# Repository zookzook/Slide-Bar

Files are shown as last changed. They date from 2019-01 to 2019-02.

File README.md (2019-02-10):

# Slide-Bar

Simple board for a slide potentiometer and visible feedback.

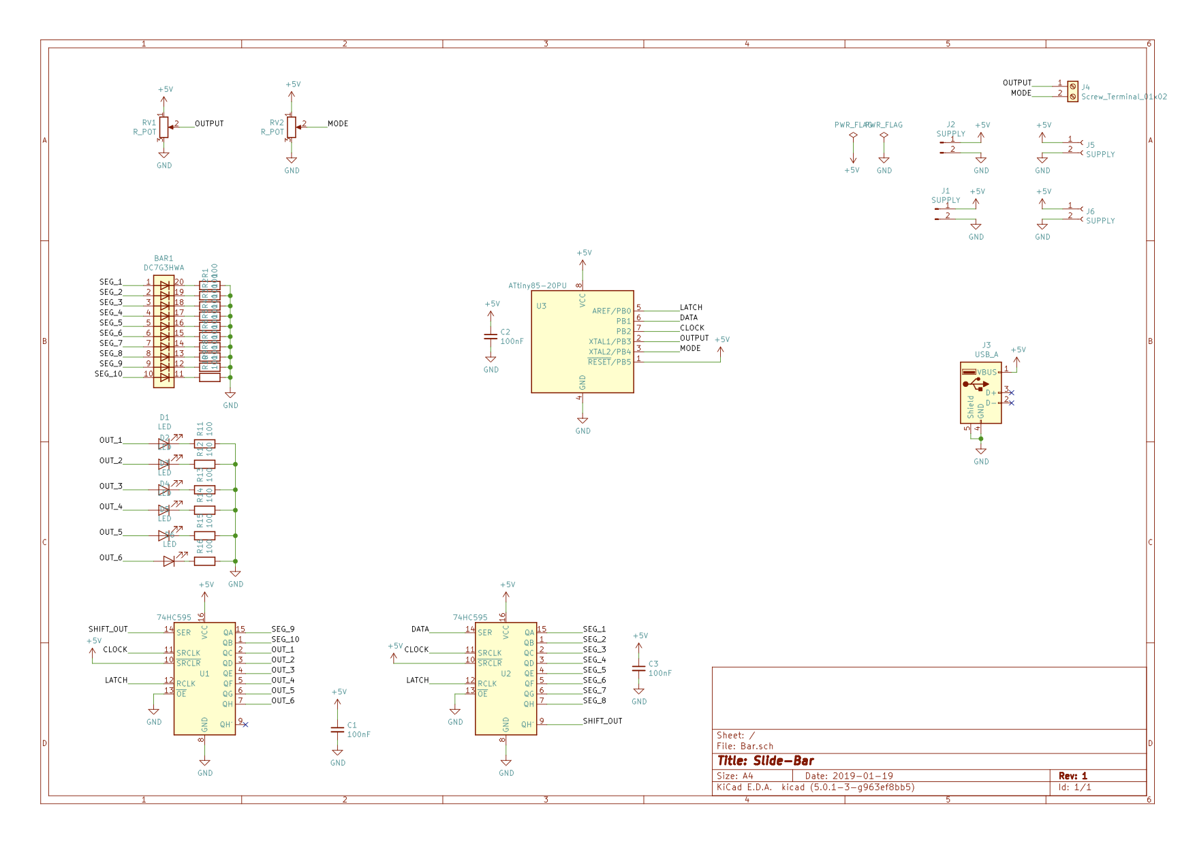
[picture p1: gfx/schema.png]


The idea behind it: With a slide potentionmeter an analog value can be changed. The change or the value is displayed with a bar display (10 LEDs). The board is designed so that you can connect several to each other. The power supply is thus forwarded from board to board.

You can thus combine the components. If you have three of the sliders, you can use the three analog values for one RGB LED. With the three slide potentionmeter thus a certain color can be adjusted.

Okay, that's a bit boring, but great fun for kids. If you add a chic frame and a nice instrument plate to the whole thing, you get a super game for children who like to fiddle around everywhere. Ultimately, that's the idea: a simple game machine and different input components (sliding and turning meters, switches) and output components (RGB LEDs, bar LEDs) with different effects (animated, cursor, Zini mode).

# How does it work?

The whole thing is controlled by an Attiny85 chip. With the help of two shift registers the LEDs are controlled. A rotary potentiometer controls the mode. There are six modes:

1) Standard slider mode: The value is displayed from bottom to top with the LEDs switched on.
2) Analogous to mode 1. The active LEDs are animated pulsatingly. In the red area, the pulse rate is higher.
3) Cursor mode. The value is displayed as a blinking cursor. If the potentiometer is changed, the flashing will be deactivated during the modification time.
4) Zini mode. When the value changes, the cursor moves, pulling a tail behind it. The previously visited LEDs are slowly faded out.
5) still in the planning stage
6) Dropping mode. A cursor is moving from the current position to the first position of the slider.

The power comes from a USB-A cable. Each two pin headers for 5V + and GND are located on the sides, so that the boards can be placed side by side or one below the other.

# Board preview
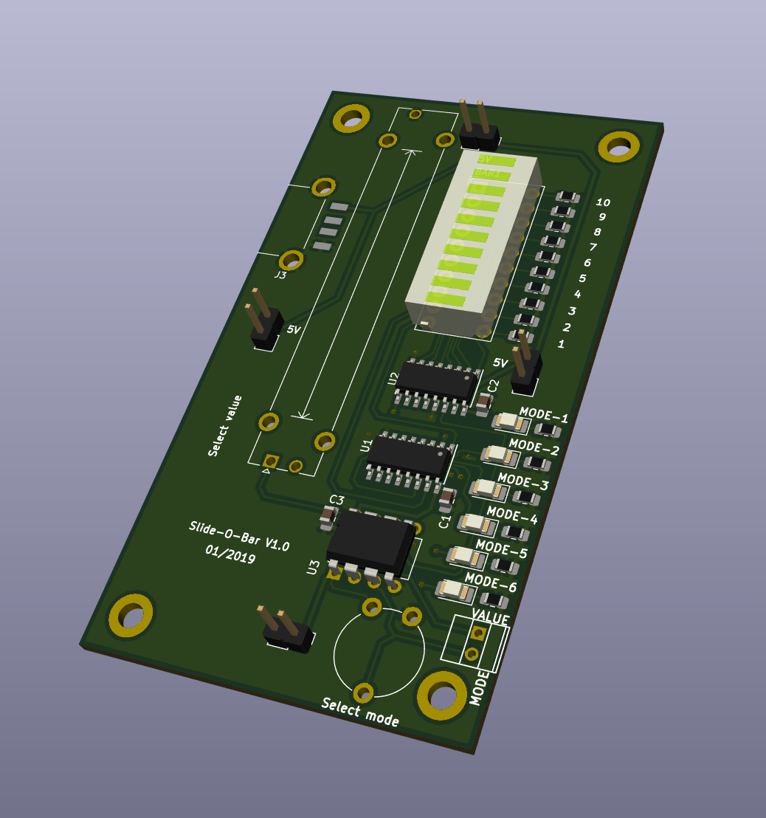
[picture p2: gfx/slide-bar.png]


You can order pretty boards from here: https://aisler.net/p/UGINGUNY

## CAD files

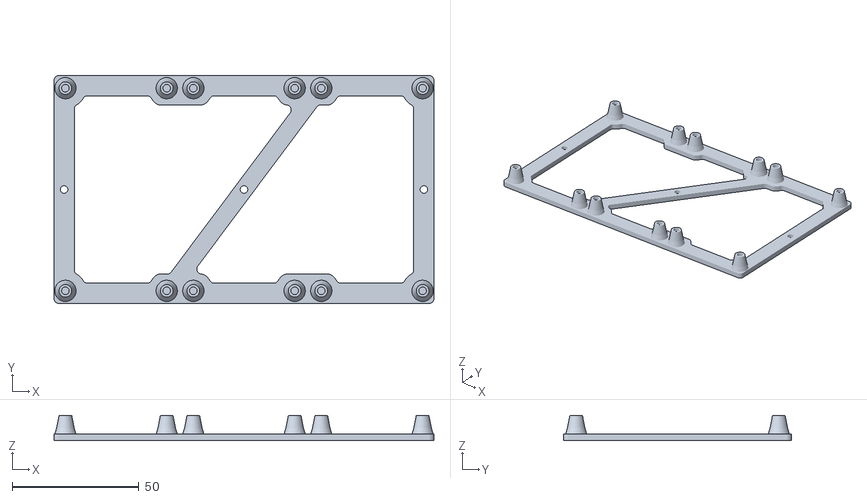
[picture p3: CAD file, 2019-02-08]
stl/mounting-3x.stl
150.0 x 90.0 x 10.0

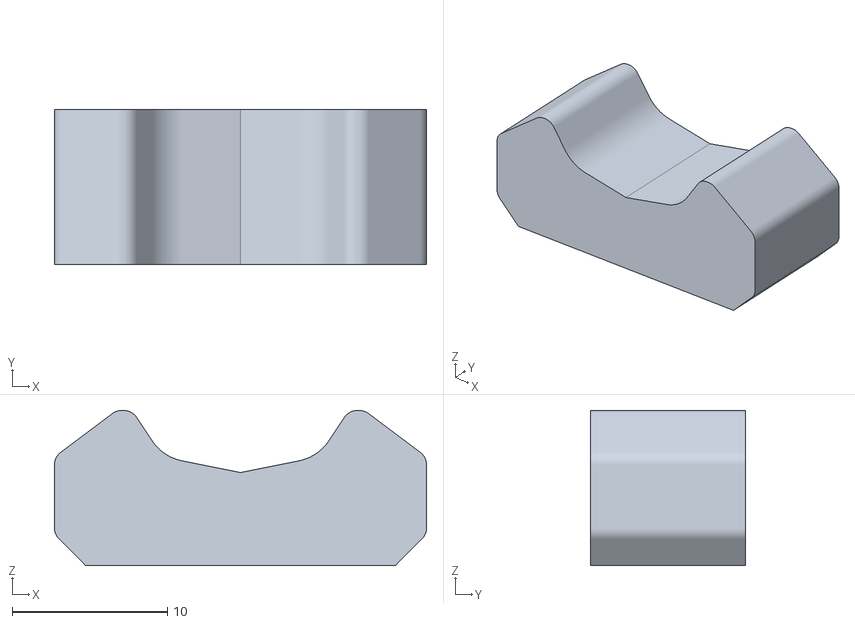
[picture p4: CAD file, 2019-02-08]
stl/slider.stl
24.0 x 10.0 x 10.0

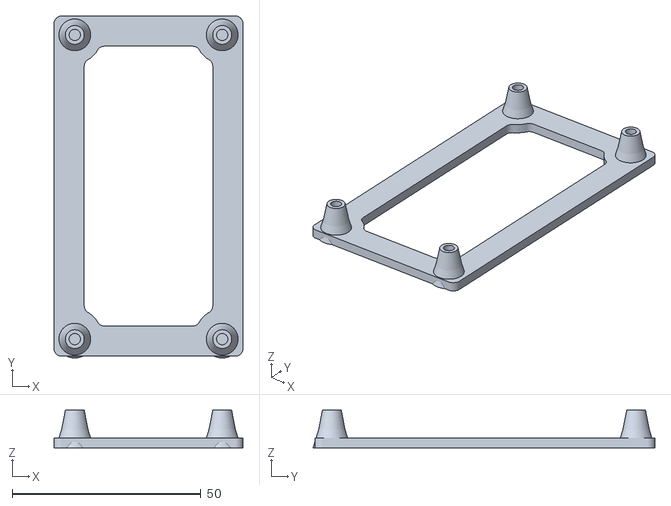
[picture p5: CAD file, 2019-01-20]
stl/mounting-1x.stl
50.0 x 90.5 x 10.0

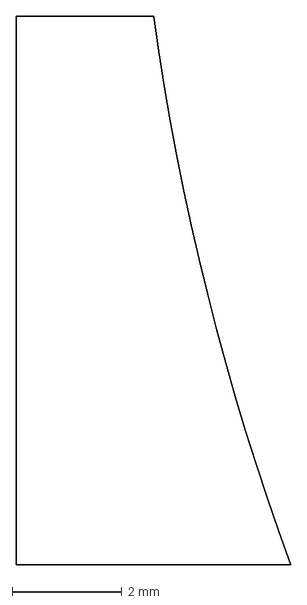
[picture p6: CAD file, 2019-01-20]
dxf/screw-holder.dxf
5.00 x 10.0 mm

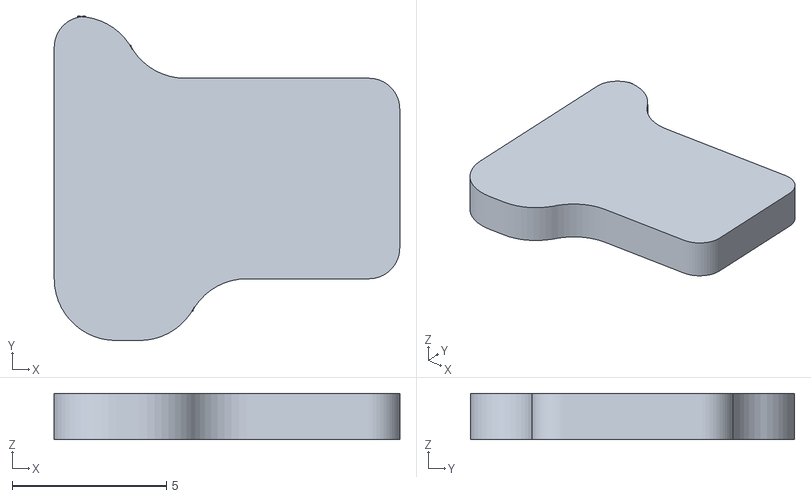
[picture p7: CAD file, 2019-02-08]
stl/washer.stl
11.2 x 10.5 x 1.50

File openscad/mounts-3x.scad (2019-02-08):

width = 50;
height = 90;
dx_1 = 5.5;
dy_1 = 5.5;
st_1 = 2.6;
h = 2.6;

module screw_holder(pos = [0,0,2] ) {
    
    translate(pos)    
    difference() {
        rotate_extrude($fn=50)
            import (file = "../dxf/screw-holder.dxf", layer = "0");
        cylinder(h = 30, r1 = 1.5, r2 = 1.5, $fn = 30, center = true);
    }
}

module mounting() {
    
    difference() {
        union() {
            linear_extrude(height = h, center = false, convexity = 1, twist = 0, slices = 20, scale = 1.0, $fn = 50)
                import (file = "../dxf/mounting-3x.dxf", layer = "0");
            
            for(i = [0 : 1 : 2]) {
                xoffset = i * 50.5;
                xpos = xoffset + 4.5;
                ypos = 5.0;                
                screw_holder([xpos, ypos, 0]);
                screw_holder([xpos + 40, ypos, 0]);
                screw_holder([xpos + 40, ypos + 80, 0]);
                screw_holder([xpos, ypos + 80, 0]);                
            }
        }
        linear_extrude(height = 10, center = true, convexity = 0, twist = 0, slices = 20, scale = 1.0, $fn = 50)
            import (file = "../dxf/mounting-3x.dxf", layer = "out");
        linear_extrude(height = 10, center = true, convexity = 0, twist = 0, slices = 20, scale = 1.0, $fn = 50)
            import (file = "../dxf/mounting-3x.dxf", layer = "out-2");

        rotate([0,0,90])
        translate([0,0,-1])
                cube([90,10,3]);

        rotate([0,0,90])
        translate([0,-(3*50+10),-1])
                cube([90,10,3]);

    }

}


mounting();

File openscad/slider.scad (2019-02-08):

module schieber() {
translate([-10,0,0])
rotate([90,0,0])
        linear_extrude(height = 12, center = true, convexity = 1, twist = 0, slices = 20, scale = 1.0, $fn = 80)
            import (file = "../dxf/slider.dxf", layer = "0");
            
}

module mounting() {
    translate([-2,-1,-0.5])
    cube([4,2,5]);
}

difference() {
    schieber();
    mounting();
}

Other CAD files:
openscad/mounts.scad
openscad/washer.scad
dxf/mounting-1x.dxf
dxf/mounting-3x.dxf
dxf/slider.dxf
dxf/washer.dxf

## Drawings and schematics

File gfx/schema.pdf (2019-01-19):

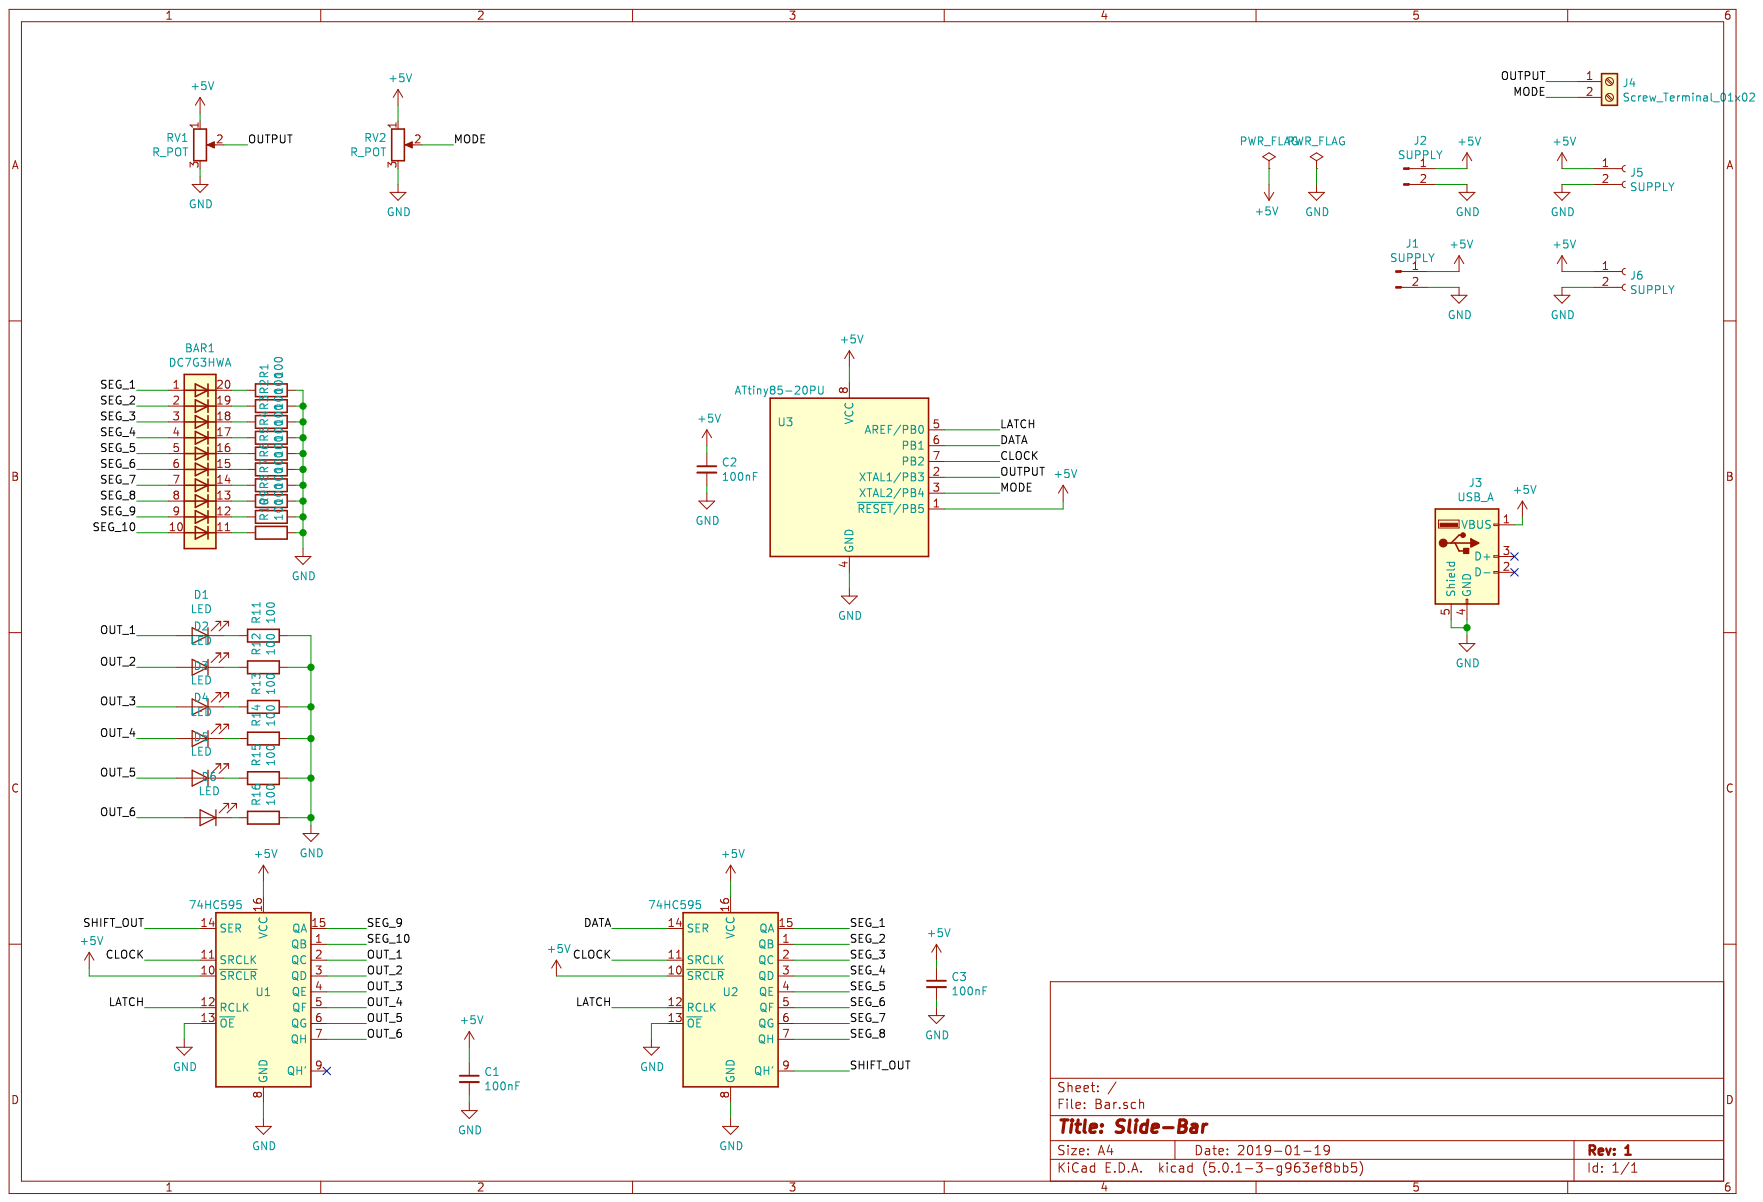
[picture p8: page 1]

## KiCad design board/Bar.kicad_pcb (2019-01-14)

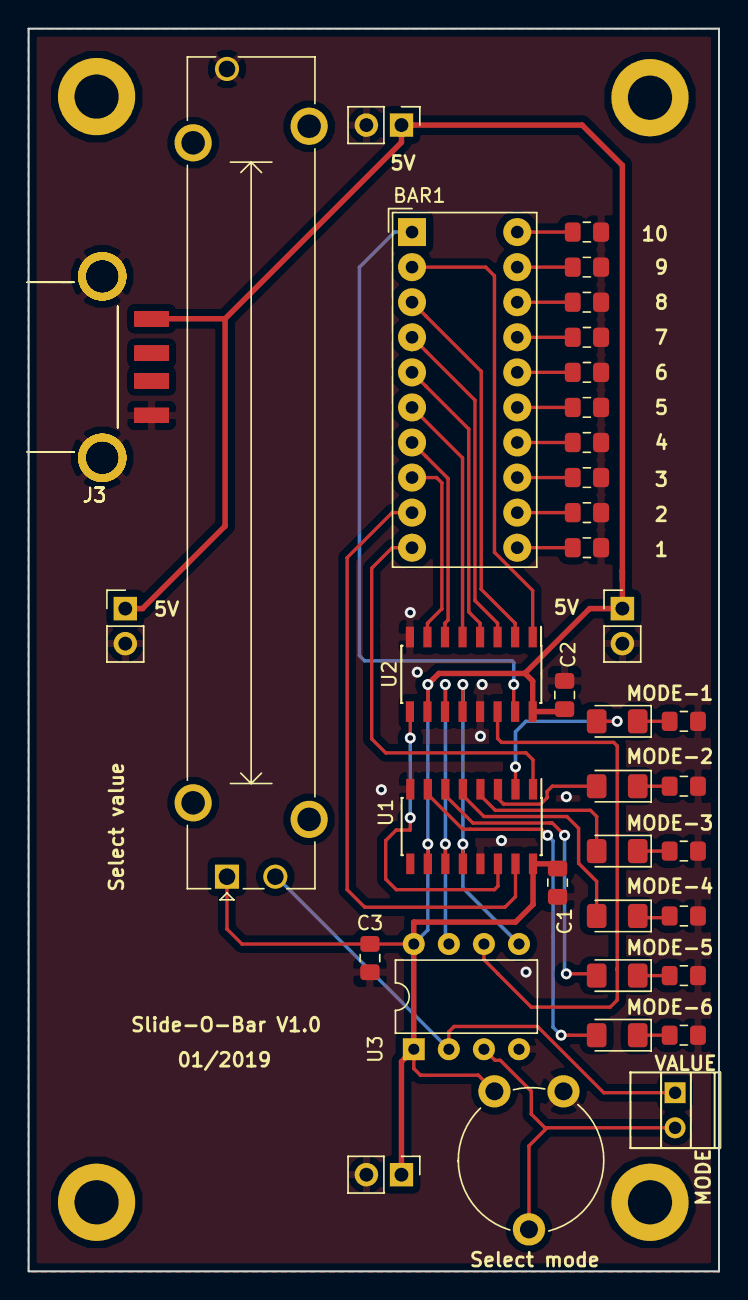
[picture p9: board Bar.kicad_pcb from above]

Board: 2 copper layers, 50.0 x 90.0 mm, 39 parts (0 on the bottom side), 42 nets.

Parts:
BAR1: DC7G3HWA; HDSP-4850
C1, C2, C3: 100nF; C_0805_2012Metric_Pad1.15x1.40mm_HandSolder
D1, D2, D3, D4, D5, D6: LED; LED_1206_3216Metric_Pad1.42x1.75mm_HandSolder
J1, J2, J5, J6: SUPPLY; PinHeader_1x02_P2.54mm_Vertical
J3, J3#2, J3#3: USB_A; LUM_2410_06_USB_A_SMD
J4: Screw_Terminal_01x02; AKZ692_2_2_54
R1, R2, R3, R4, R5, R6, R7, R8, R9, R10, R11, R12, R13, R14, R15, R16: 100; R_0805_2012Metric_Pad1.15x1.40mm_HandSolder
RV1: R_POT; Potentiometer_Bourns_PTA4543_Single_Slide
RV2: R_POT; Potentiometer_Piher_PT-10-V10_Vertical
U1, U2: 74HC595; SOIC-16_3.9x9.9mm_P1.27mm
U3: ATtiny85-20PU; DIP-8_W7.62mm

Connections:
+5V: C1.1, C2.1, C3.1, J1.1, J2.1, J3.1, J3#2.1, J3#3.1, J5.1, J6.1, RV1.1, RV2.1, U1.10, U1.16, U2.10, U2.16, U3.1, U3.8
/CLOCK: U1.11, U2.11, U3.7
/DATA: U2.14, U3.6
/LATCH: U1.12, U2.12, U3.5
/MODE: J4.2, RV2.2, U3.3
/OUTPUT: J4.1, RV1.2, U3.2
/OUT_1: D1.2, U1.2
/OUT_2: D2.2, U1.3
/OUT_3: D3.2, U1.4
/OUT_4: D4.2, U1.5
/OUT_5: D5.2, U1.6
/OUT_6: D6.2, U1.7
/SEG_1: BAR1.1, U2.15
/SEG_2: BAR1.2, U2.1
/SEG_3: BAR1.3, U2.2
/SEG_4: BAR1.4, U2.3
/SEG_5: BAR1.5, U2.4
/SEG_6: BAR1.6, U2.5
/SEG_7: BAR1.7, U2.6
/SEG_8: BAR1.8, U2.7
/SEG_9: BAR1.9, U1.15
/SEG_10: BAR1.10, U1.1
/SHIFT_OUT: U1.14, U2.9
GND: C1.2, C2.2, C3.2, J1.2, J2.2, J3.4, J3.5, J3#2.4, J3#2.5, J3#3.4, J3#3.5, J5.2, J6.2, R1.2, R2.2, R3.2, R4.2, R5.2, R6.2, R7.2, R8.2, R9.2, R10.2, R11.2, R12.2, R13.2, R14.2, R15.2, R16.2, RV1.3, RV2.3, U1.8, U1.13, U2.8, U2.13, U3.4
unnamed: BAR1.11, R10.1
unnamed: BAR1.12, R9.1
unnamed: BAR1.13, R8.1
unnamed: BAR1.14, R7.1
unnamed: BAR1.15, R6.1
unnamed: BAR1.16, R5.1
unnamed: BAR1.17, R4.1
unnamed: BAR1.18, R3.1
unnamed: BAR1.19, R2.1
unnamed: BAR1.20, R1.1
unnamed: D1.1, R11.1
unnamed: D2.1, R12.1
unnamed: D3.1, R13.1
unnamed: D4.1, R14.1
unnamed: D5.1, R15.1
unnamed: D6.1, R16.1
unnamed: J3.2, J3#2.2, J3#3.2
unnamed: J3.3, J3#2.3, J3#3.3

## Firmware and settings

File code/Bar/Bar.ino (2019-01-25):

/**
 * 
 */
#include <tinySPI.h>
#include <avr/io.h>
#include <avr/interrupt.h>
#include "types.h"
#include "mode_1.h"
#include "mode_2.h"
#include "input.h"

const int LATCH_PIN = 0;
const int DATA_PINPIN = 1;
const int CLOCK_PIN = 2;    

void (*fun_ptr)(void) = NULL; 

LED LEDS[MAX_BARS];

int current_mode = 0;

volatile byte i = 0;

void init_timer_1(void) {
  
  TCCR1 |= (1 << CTC1);     // clear timer on compare match
  TCCR1 |= (1 << CS13) | (1 << CS11) | (1 << CS10); //
  OCR1C = 0;                // compare match value 
  TIMSK |= (1 << OCIE1A);   // enable compare match interrupt
}

void pwm(void) {

  i += 5;
  unsigned int w = 0x0000;
  int          j = 0;
  
  while(j < MAX_BARS) {
    w = w << 1;
    w = w | (LEDS[j].current > i);
    j++;
  }

  w = w | get_mode_mask();
  write_word(w);
  
}

ISR(TIMER1_COMPA_vect) {
  (*fun_ptr)(); 
}

void write_word(int data) {
    
    PORTB &= ~B00000001; // digitalWrite(LATCH_PIN, LOW);
    SPI.transfer(data >> 8);
    SPI.transfer(data); // digitalWrite(LATCH_PIN, HIGH);       
    PORTB |= B00000001;
}

void run_test() {
  write_word(0xffff);  
  delay(3000);
  write_word(0x0000);  
  delay(1000);
}

void set_pwm() {
  fun_ptr = &pwm;
}

void setup() {

  for(int i = 0; i < MAX_BARS; i++ ) {
    LEDS[i].current = 0;
  }
  
  SPI.begin();     

  pinMode(LATCH_PIN, OUTPUT);    // latch pin needs to be set up for hardware or software
  digitalWrite(LATCH_PIN, HIGH);
    
  run_test();
  set_pwm();
  init_timer_1();        // initialize timer registers  
  sei();
}

void loop() {
  check_mode();
}

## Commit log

2019-01-02 added leds for representing the mode added first version of the software
    [Bar.kicad_pcb, Bar.sch]
2019-01-03 using spi, added code for different modes, added filter for the analog input
    [Bar.sch]
2019-01-03 using A2 for selecting operation mode
    [Bar.sch]
2019-01-14 final board
    [Bar.kicad_pcb, Bar.sch]
2019-01-19 Updated schema and board preview
2019-01-20 added files for mounting (3d printing)
    [Bar.sch, mounting-1x.dxf, mounting-1x.stl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]
2019-01-20 clean up code
    [mounts.scad]
2019-01-20 added mounting bracket for three boards
    [mounting-3x.dxf, mounting-3x.stl, mounts.scad]
2019-01-25 added mode 5 + 6, flipped bar order
    [mounting-3x.dxf]
2019-02-08 added 3d models
    [mounting-3x.stl, mounts-3x.scad, mounts.scad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]
